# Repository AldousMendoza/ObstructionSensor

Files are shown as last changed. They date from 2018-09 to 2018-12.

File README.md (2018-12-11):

# Obstruction Sensor

This is my first attempt in making a device using the raspberry pi.  
This project mainly presents the VL53L0X ToF(Time of Flight) Distance Sensor.  

A bit of an introduction on how the VL53L0X works:  
The VL53L0X emmits a laser towards a direction.
It then calculates for the distance based on how long the laser bounces back.

## Build Instructions

### System Diagram
The VL53L0X continously reads data(distance) while the SSD1306 continously displays that data.
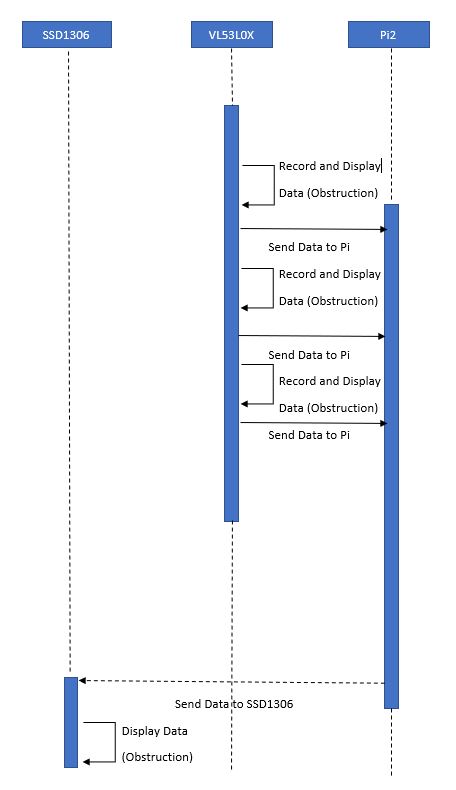
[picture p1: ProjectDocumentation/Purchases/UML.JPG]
  

### [Budget and Parts](https://github.com/AldousMendoza/ObstructionSensor/blob/master/ProjectDocumentation/Budget.xlsx)
You will be needing the following parts in order to create the obstruction sensor:  
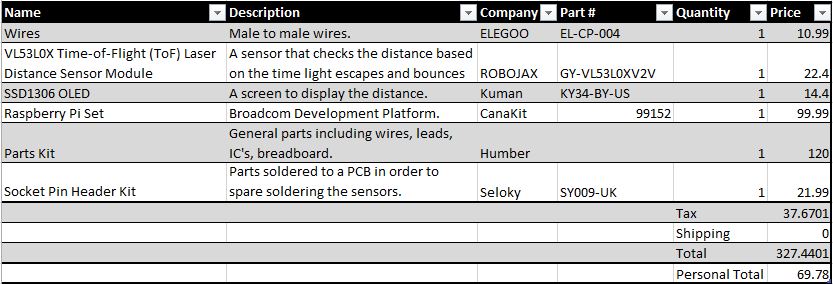
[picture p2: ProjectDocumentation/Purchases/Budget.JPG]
  
NOTE: The Socket Pin Headers are optional, depends if you will be building the PCB or not.  

### Assembly
Raspberry Pi 2 Pin Layout  
  

VL53L0X Pin Layout  
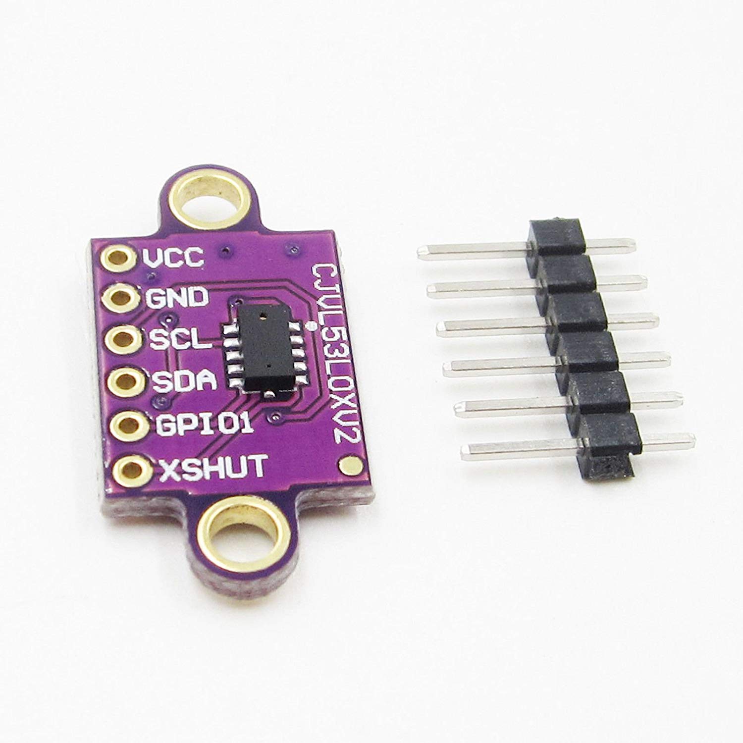
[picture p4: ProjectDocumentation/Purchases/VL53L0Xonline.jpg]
  

SSD1306 Pin Layout  
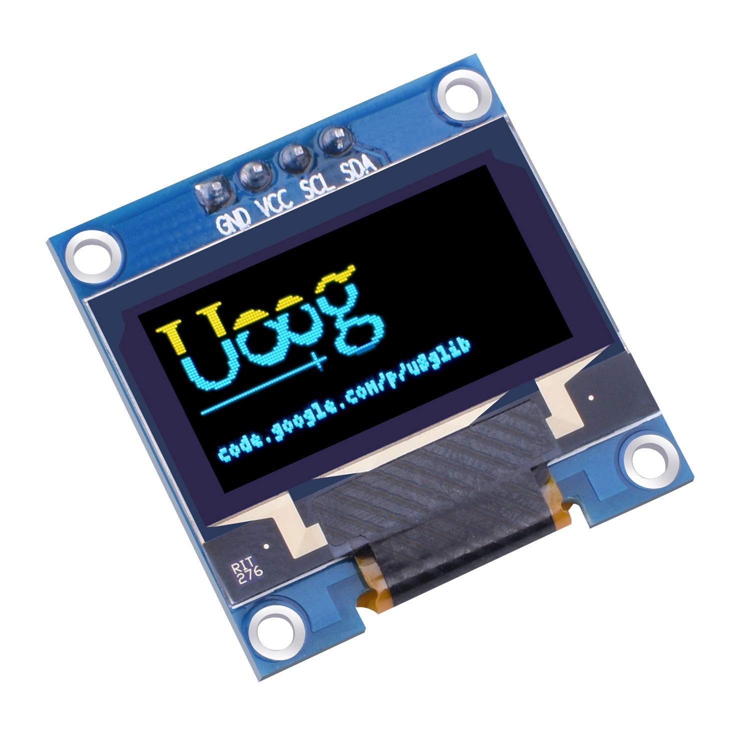
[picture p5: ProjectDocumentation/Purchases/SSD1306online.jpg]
  

1. Connect the VL53L0X and SSD1306's VCC pin to the Raspberry Pi's 3v3 pin.  
2. Connect the  VL53L0X and SSD1306's GND pin to any of the Raspberry Pi's GND pin.  
3. Connect the VL53L0X and SSD1306's SDA pin to the Raspberry Pi's SDA pin.  
4. Connect the VL53L0X and SSD1306's SLA pin to the Raspberry Pi's SLA pin.  

Your assembly should look similar to this:  
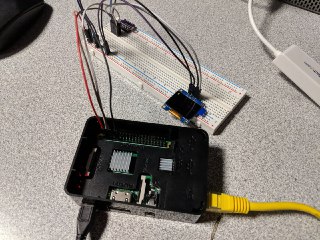
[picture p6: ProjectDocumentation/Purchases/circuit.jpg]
  

### [PCB](https://github.com/AldousMendoza/ObstructionSensor/blob/master/ProjectDocumentation/Obstruction%20Sensor%20PCB%20Sketch.fzz)
This is entirely optional, you do not need this for the device to work.  
For the PCB, you will need the program, Fritzing.  
This is how the PCB will look like this:  
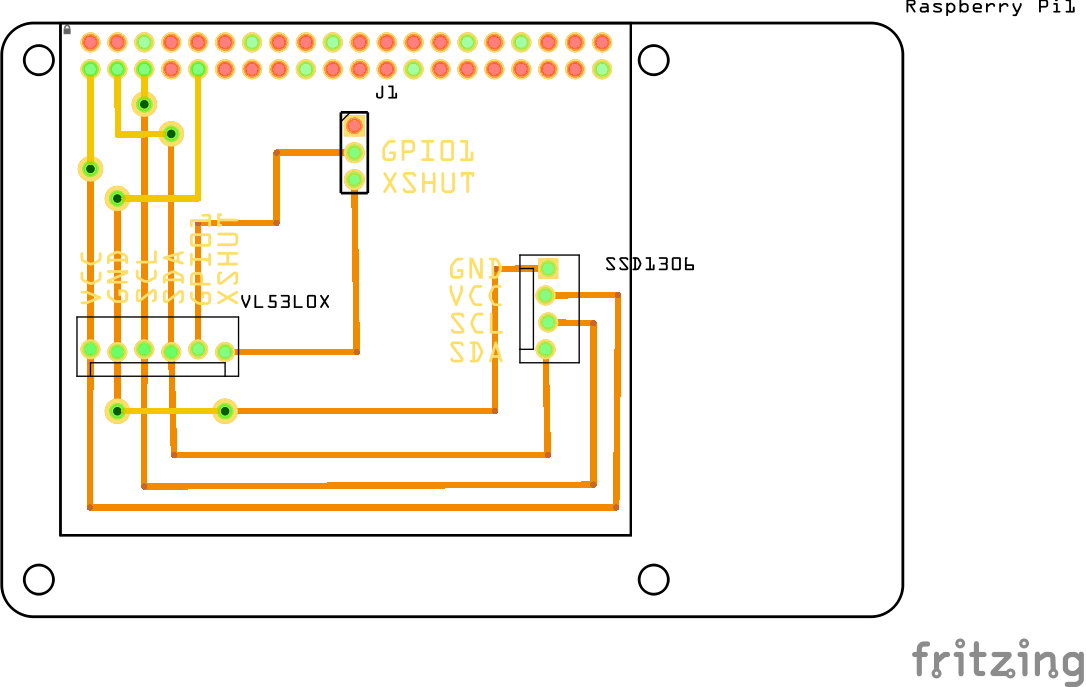
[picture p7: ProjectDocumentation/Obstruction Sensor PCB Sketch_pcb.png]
  

### [Enclosure](https://github.com/AldousMendoza/ObstructionSensor/blob/master/ProjectDocumentation/Pi2CaseX6%20-%20Obstruction%20Sensor.cdr)
This is also optional.  
For the enclosure, we will be using a laser cutter along with the program, CorelDRAW.  
This is how the Enclosure will be:  
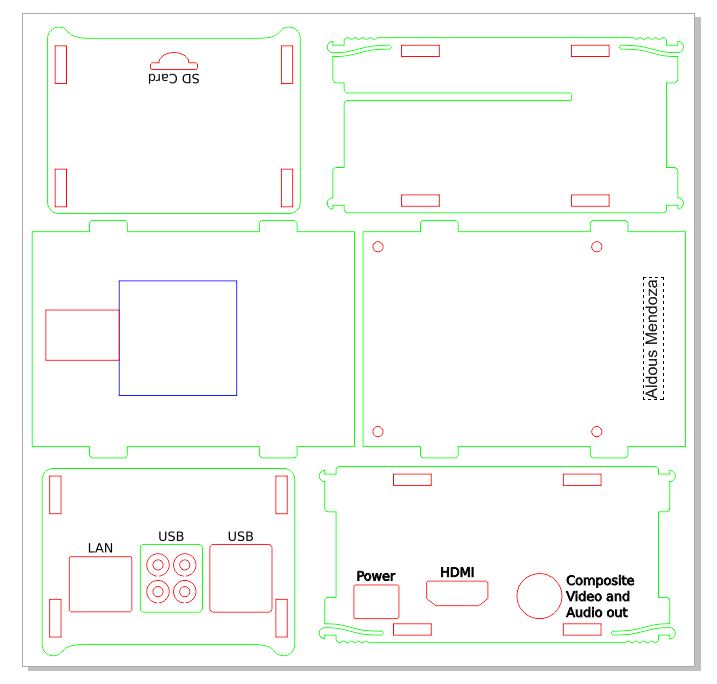
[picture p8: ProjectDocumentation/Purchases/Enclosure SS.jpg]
  

And this is how it looks after assembly:  
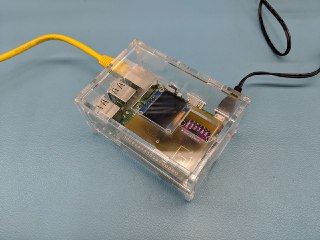
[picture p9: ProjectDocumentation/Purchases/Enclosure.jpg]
  

### Software and Setup

1. Clone and follow the instructions for [VL53L0X](https://github.com/adafruit/Adafruit_CircuitPython_VL53L0X) from [Adafruit](https://github.com/adafruit), credits to them.  
2. Clone and follow the instructions for [SSD1306](https://github.com/adafruit/Adafruit_CircuitPython_SSD1306) from [Adafruit](https://github.com/adafruit), credits to them.  
3. Download all the files in this [folder](https://github.com/AldousMendoza/ObstructionSensor/tree/master/ProjectDocumentation/O-Sensor) to your raspberry pi  

The actual code to run it is the text.py located inside the folder.  
Run it using "Python3 test.py".

### [Schedule](https://github.com/AldousMendoza/ObstructionSensor/blob/master/ProjectDocumentation/Project%20Schedule.mpp)
Having all the parts, and excluding PCB and Enclosure creation times, the project can be made in less than a day.

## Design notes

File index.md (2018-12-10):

## Week 15 : [Build Instructions](https://github.com/AldousMendoza/ObstructionSensor/blob/master/README.md)

## Week 13 - 14 : [Project Presentation](https://github.com/AldousMendoza/ObstructionSensor/blob/master/ProjectDocumentation/Obstruction%20Sensor.pptx)
Updated code to display VL53L0X results to the SSD1306.
The module I acquired did not support text display, only pixel coordinates.
Created code to display numbers 1-10 and 'm' in a 5x10 grid.

## Week 12 : [Enclosure Due](https://github.com/AldousMendoza/ObstructionSensor/blob/master/ProjectDocumentation/Pi2CaseX6%20-%20Obstruction%20Sensor.cdr)
Screenshot of the CorelDRAW file.  
  
This is the finished product.  


## Week 11 : Power-Up Milestone
I have received the socket pin headers and soldered them to my board.
The VL53L0X(ToF) and SSD1306(OLED) are working as intended.
Next in line is to adjust the code to support numbers and a few letters, then to display the distance calculation on the OLED.  
Budget is unchanged.  
Project is now back on [schedule](https://github.com/AldousMendoza/ObstructionSensor/blob/master/ProjectDocumentation/Project%20Schedule.mpp).

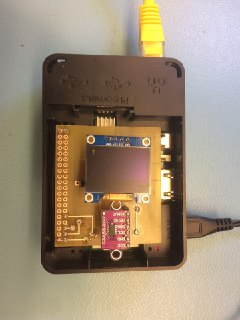
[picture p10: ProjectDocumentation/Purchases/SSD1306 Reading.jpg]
  
SSD1306 - Adafruit's module has no text support, only able to display pixels using coordinate manipulation. Made code to display the letter 'T'.  
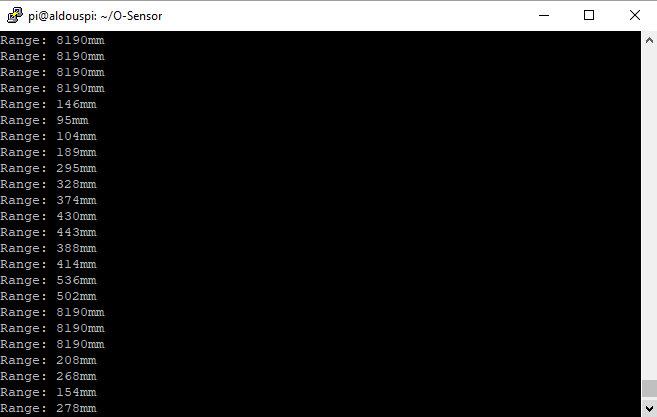
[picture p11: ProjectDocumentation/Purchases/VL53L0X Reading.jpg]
  
VL53L0X - Reading distance and displaying it on the monitor. (in progress: to the OLED)

### Update
[Budget](https://github.com/AldousMendoza/ObstructionSensor/blob/master/ProjectDocumentation/Budget.xlsx) updated.

## Week 10 : PCB Assembly
Unfortunately the item that I purchased was a crimp pin header toolkit.
It was not the part I needed.
I will not count this with my purchased items as I won't be needing this as of yet.
I will be purchasing the socket pin headers sometime this week.
I am now slightly behind [schedule](https://github.com/AldousMendoza/ObstructionSensor/blob/master/ProjectDocumentation/Project%20Schedule.mpp) because of this mishap.
On a sidenote, I was able to acquire a 40x2 socket pin header, and soldered it on my board.

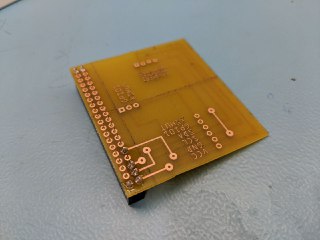
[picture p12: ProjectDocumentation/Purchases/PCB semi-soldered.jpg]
  
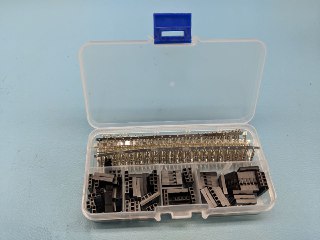
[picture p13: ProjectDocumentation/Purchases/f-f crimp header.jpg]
  
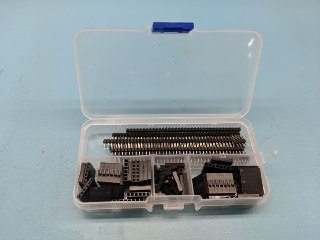
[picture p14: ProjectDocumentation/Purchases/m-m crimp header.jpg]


## Week 9 : [PCB Creation](https://github.com/AldousMendoza/ObstructionSensor/blob/master/ProjectDocumentation/Obstruction%20Sensor%20PCB%20Sketch.fzz)
Gerber file has been sent to prototypelab@humber.ca

### Status Report
Financial Status: Budget has been surpassed.  
Schedule: The project is on [schedule](https://github.com/AldousMendoza/ObstructionSensor/blob/master/ProjectDocumentation/Project%20Schedule.mpp).  
Programming has already been started, trying to figure out how to change the I2C address of the VL53L0X to 24 (default 29) using software.  

  

### UPDATE:  
i2c address table:  
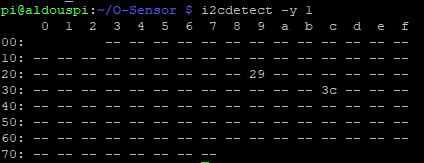
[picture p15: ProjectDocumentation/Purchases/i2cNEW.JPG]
  

Connection has been changed  
  

New Display purchased (SSD1306)  
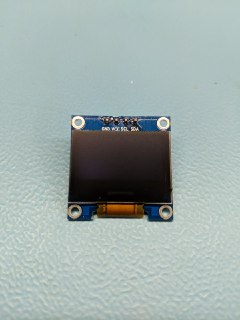
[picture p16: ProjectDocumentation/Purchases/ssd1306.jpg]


## Week 8 : Breadboard

### Resolution
I dropped by Humber's prototype lab to seek help.
The device was still not being detected by their platform.
It doesn't help that we couldn't find the datasheet for the specific board I had, as the device has different setups depending on how the board was laid out.
After troubleshooting and tracing the board, they hinted that one of the pins on the sensor attached to the board had a tiny smudge of solder that connected it to another pin on the sensor.
I am proud to announce that the pins I soldered were not contributing to the issue.
Nonetheless, I will not rule myself out in possibly causing this issue because even though the shorted pins were on the opposite side of the pins I soldered, it is still possible that I have splashed a tiny amount of solder on the opposite side (be very careful on soldering).
After removing they smudge, being as careful as possible as the sensor is very small, the device was now being detected.
Below is the screenshot of the default address it has (0x29).
I still have to change it to 0x24, which will require me more time as it will be changed thru software, rather than hardware.
I am just glad that I did not need to buy another sensor as the shipping fee on Adafruit is expensive.
Shout-outs to Vlad and Kelly as they really saved me here.  
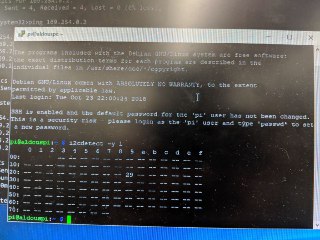
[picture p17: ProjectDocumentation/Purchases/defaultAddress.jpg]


### Issue
The wiring is correct as I tested other's sensors with i2cdetect -y 1, and their devices showed up.
Mine does not show up, I already checked the soldering with the microscope and do not see any issues.
I also checked the voltage on the multimeter and oscilloscope, based on my research, the voltage should spike when using the i2cdetect command.
It is having a constant voltage, which for me, suggests that the board is defective.
I will go and ask help from Kelly and Vlad tomorrow as the lab is closed for today.
If the issue persists after tomorrow, I will purchase a new sensor from Adafruit, a company well trusted.  
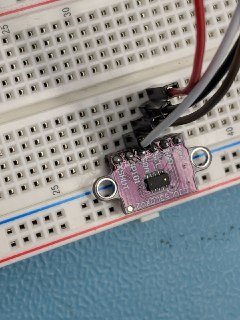
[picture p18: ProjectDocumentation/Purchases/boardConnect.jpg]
  
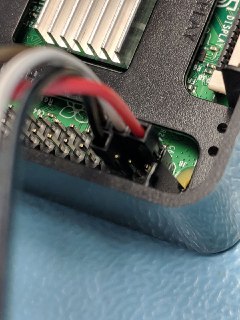
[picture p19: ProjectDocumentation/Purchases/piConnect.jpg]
  
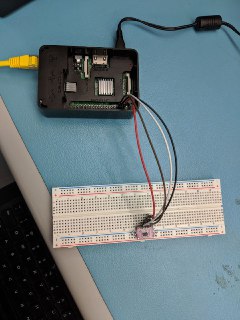
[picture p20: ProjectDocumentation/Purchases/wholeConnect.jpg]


## Week 7 : Purchased Parts
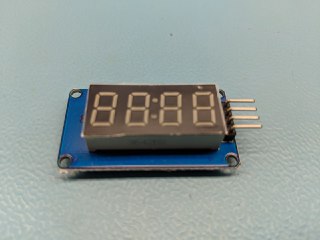
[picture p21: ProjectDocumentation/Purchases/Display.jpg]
  
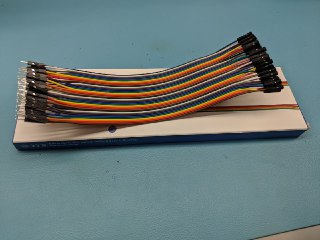
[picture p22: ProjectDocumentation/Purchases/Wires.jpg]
  
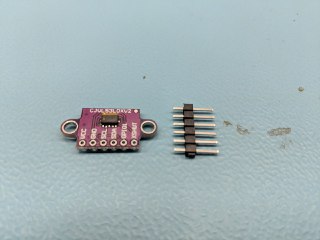
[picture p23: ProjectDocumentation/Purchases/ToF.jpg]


## Week 6 : Holiday

## Week 5 : [Purchases](https://github.com/AldousMendoza/ObstructionSensor/blob/master/ProjectDocumentation/Purchases.docx)  
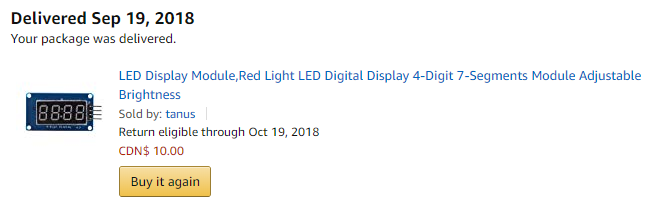
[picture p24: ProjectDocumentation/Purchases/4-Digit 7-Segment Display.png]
  
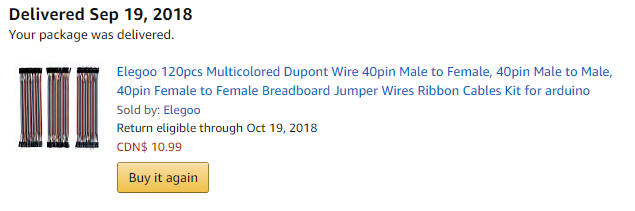
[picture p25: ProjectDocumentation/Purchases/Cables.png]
  
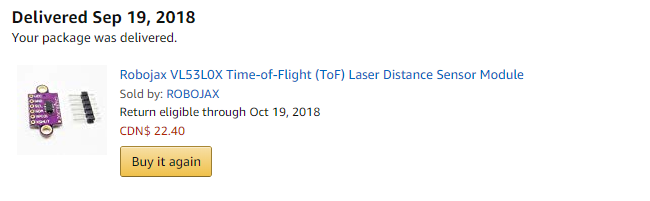
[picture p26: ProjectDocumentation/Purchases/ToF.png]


## Week 4 : [Budget](https://github.com/AldousMendoza/ObstructionSensor/blob/master/ProjectDocumentation/Budget.xlsx)

## Week 3 : [Project Schedule](https://github.com/AldousMendoza/ObstructionSensor/blob/master/ProjectDocumentation/Project%20Schedule.mpp)

## Week 2 : [Project Proposal](https://github.com/AldousMendoza/ObstructionSensor/blob/master/ProjectDocumentation/Project%20Proposal.xlsx)

## Week 1 : Debriefing

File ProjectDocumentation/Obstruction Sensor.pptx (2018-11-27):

## Obstruction Sensor

Aldous Mendoza

## Proposal

Obstruction Sensor (https://aldousmendoza.github.io/ObstructionSensor/)
Automated devices rely on sensors to make majority of their decisions. Self driving devices require obstruction sensors to avoid collisions, and even decide how slow it is going to be.

SSD1306(oLED)
VL53L0X(ToF)


## Budget

Amazon.ca

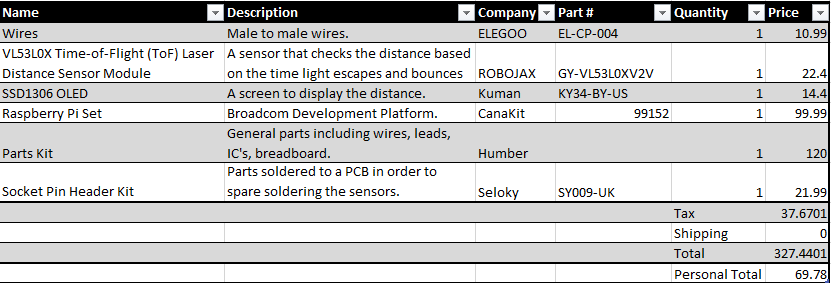
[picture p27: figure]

## Schedule

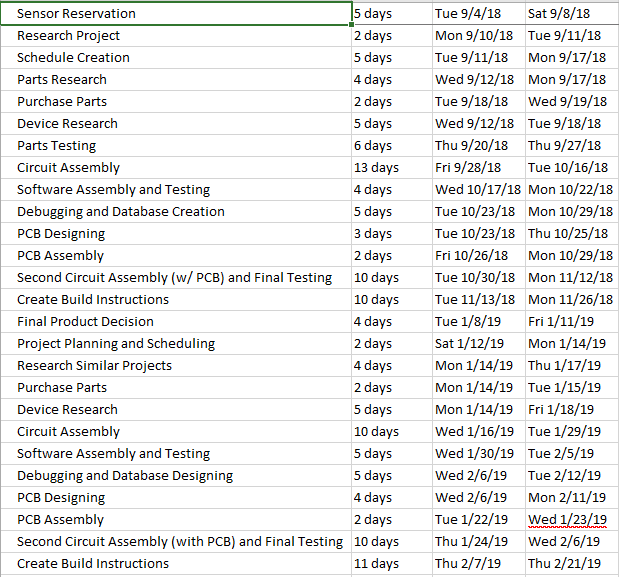
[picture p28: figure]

## Images

Reading
i2c Address
Enclosure

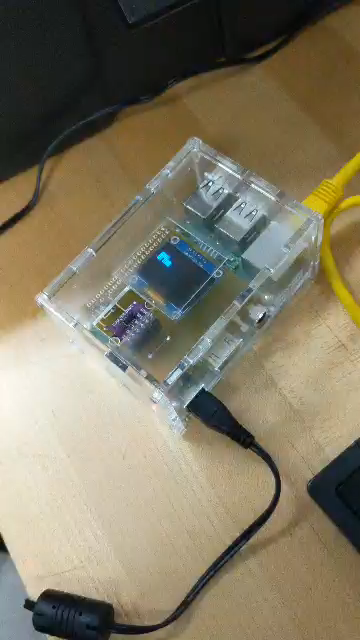
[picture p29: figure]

## Knowledge

- Electric Circuits (TECH101) and Electronic Circuits (CENG150) – assisted with proper circuit building.
- Technical Mathematics 1 (TMTH104) – assisted with problem solving, and algorithms.
- Programming in C (TECH153) and Object Oriented Programming using Java (CENG217)– assisted with learning python.
- Technical Reading and Writing Skills (WRIT120) and Introduction to Software Engineering (CENG216) – assisted with documents.

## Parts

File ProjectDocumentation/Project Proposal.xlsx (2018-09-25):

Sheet: DataEntry
Submission Date | 2018-09-11
Project Name | Obstruction Sensor
Student Name | Aldous Mendoza
Project repository | https://github.com/AldousMendoza/ObstructionSensor
SensorEffector choice | VL53L0x ToF distance (0x24)
The database will store | Obstruction distance. We also plan on storing temparature, and humidity information from the RC car in order to prevent further damage when overheating.
The mobile device functionality will include | A "start" button. We also plan on making an automated RC car that will autodetect obstructions and make its way thru a small maze. The final functionality will most likely consist of "forward" and "reverse" buttons.
I will be collaborating with the following company/department | None
My group in the winter semester will include | Abiodum Ojo, Duke
50 word problem statement | Automated devices do not have their own obstruction sensors. They will need separate modules that are able to give information to the device so that they will be able to prevent collisions.
100 words of background | For automated devices like self driving cars and the like, there is always the issue of collision. Usually, these devices rely on other sensors for it to make the best decision. Without these sensors, the self driving car will always think that it is in the clear and will accelerate even when there is an obstruction, causing accidents.
Current product APA citation | Adafruit (2016, November 23). Adafruit VL53L0X Time of Flight Distance Sensor - ~30 to 1000mm. https://www.adafruit.com/product/3317
Existing research IEEE paper APA citation
Brief description of planned purchases | 1 VL53L0x ToF Distance Sensor, 4 (front, left, right, back) in the winter semester for the RC car.
Solution description | A VL53L0x ToF Distance Sensor calculates the distance from one object to another. In this case, the RC car to any kind of obstruction. After getting information (distance) from the device, through appropriate programming, the RC car should turn accordingly. Multiple sensors will guide the RC car to make the best decision (turning left, turning right, or even a complete stop).

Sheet: DataBase
Submission Date | Project Name | Student Name | Project repository | SensorEffector choice | The database will store | The mobile device functionality will include | I will be collaborating with the following company/department | My group in the winter semester will include | 50 word problem statement | 100 words of background | Current product APA citation | Existing research IEEE paper APA citation | Brief description of planned purchases | Solution description
43354 | Obstruction Sensor | Aldous Mendoza | https://github.com/AldousMendoza/ObstructionSensor | VL53L0x ToF distance (0x24) | Obstruction distance. We also plan on storing temparature, and humidity information from the RC car in order to prevent further damage when overheating. | A "start" button. We also plan on making an automated RC car that will autodetect obstructions and make its way thru a small maze. The final functionality will most likely consist of "forward" and "reverse" buttons. | None | Abiodum Ojo, Duke | Automated devices do not have their own obstruction sensors. They will need separate modules that are able to give information to the device so that they will be able to prevent collisions. | For automated devices like self driving cars and the like, there is always the issue of collision. Usually, these devices rely on other sensors for it to make the best decision. Without these sensors, the self driving car will always think that it is in the clear and will accelerate even when there is an obstruction, causing accidents. | Adafruit (2016, November 23). Adafruit VL53L0X Time of Flight Distance Sensor - ~30 to 1000mm. https://www.adafruit.com/product/3317 | 0 | 1 VL53L0x ToF Distance Sensor, 4 (front, left, right, back) in the winter semester for the RC car. | A VL53L0x ToF Distance Sensor calculates the distance from one object to another. In this case, the RC car to any kind of obstruction. After getting information (distance) from the device, through appropriate programming, the RC car should turn accordingly. Multiple sensors will guide the RC car to make the best decision (turning left, turning right, or even a complete stop).

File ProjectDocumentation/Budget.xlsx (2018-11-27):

Obstruction Sensor Budget
Name | Description | Company | Part # | Quantity | Price
Wires | Male to male wires. | ELEGOO | EL-CP-004 | 1 | 10.99
VL53L0X Time-of-Flight (ToF) Laser Distance Sensor Module | A sensor that checks the distance based on the time light escapes and bounces back. | ROBOJAX | GY-VL53L0XV2V | 1 | 22.4
SSD1306 OLED | A screen to display the distance. | Kuman | KY34-BY-US | 1 | 14.4
Raspberry Pi Set | Broadcom Development Platform. | CanaKit | 99152 | 1 | 99.99
Parts Kit | General parts including wires, leads, IC's, breadboard. | Humber |  | 1 | 120
Socket Pin Header Kit | Parts soldered to a PCB in order to spare soldering the sensors. | Seloky | SY009-UK | 1 | 21.99
 |  |  |  | Tax | 37.6701
 |  |  |  | Shipping | 0
 |  |  |  | Total | 327.4401
 |  |  |  | Personal Total | 69.78
Aldous Mendoza

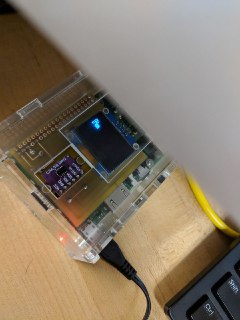
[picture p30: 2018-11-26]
ProjectDocumentation/Purchases/displayReading.jpg

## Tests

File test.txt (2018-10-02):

## Obstruction Sensor

### Week 5 -[Submitted Purchases](https://github.com/AldousMendoza/ObstructionSensor/blob/master/ProjectDocumentation/Purchases.docx)  
  
  
  

### Week 4 - [Submitted Budget](https://github.com/AldousMendoza/ObstructionSensor/blob/master/ProjectDocumentation/Budget.xlsx)

### Week 3 - [Submitted Project Schedule](https://github.com/AldousMendoza/ObstructionSensor/blob/master/ProjectDocumentation/Project%20Schedule.mpp)

### Week 2 - [Submitted Project Proposal](https://github.com/AldousMendoza/ObstructionSensor/blob/master/ProjectDocumentation/Project%20Proposal.xlsx)

### Week 1 - Debriefing

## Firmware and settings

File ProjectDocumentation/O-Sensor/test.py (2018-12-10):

# Test demo
import time

import board
import busio

import adafruit_ssd1306
import adafruit_vl53l0x

# Initialize I2C bus
i2c = busio.I2C(board.SCL, board.SDA)
vl53 = adafruit_vl53l0x.VL53L0X(i2c)
oled = adafruit_ssd1306.SSD1306_I2C(128, 32, i2c)

text = 'Hello'

#make a stupid-ass letter 'T'
#make it 6x6 and with 2 pixels thick
oled.fill(0)
#oled.pixel(0,0,1)
#oled.pixel(1,0,1)
#oled.pixel(2,0,1)
#oled.pixel(3,0,1)
#oled.pixel(4,0,1)
#oled.pixel(2,1,1)
#oled.pixel(2,2,1)
#oled.pixel(2,3,1)
#oled.pixel(2,4,1)
#oled.show()

# Optionally adjust the measurement timing budget to change speed and accuracy.
# See the example here for more details:
#   https://github.com/pololu/vl53l0x-arduino/blob/master/examples/Single/Single.ino
# For example a higher speed but less accurate timing budget of 20ms:
#vl53.measurement_timing_budget = 20000
# Or a slower but more accurate timing budget of 200ms:
#vl53.measurement_timing_budget = 200000
# The default timing budget is 33ms, a good compromise of speed and accuracy.

# Main loop will read the range and print it every second.
while True:
    time.sleep(1.0)
    num = 0
    xStart = 0
    yStart = 8
    range = format(vl53.range)
    print('Range: %smm' % (range))

    L = list(range)
    for x in L:
        if x == '0':
            oled.pixel(xStart, yStart, 1)
            oled.pixel(xStart, yStart + 1, 1)
            oled.pixel(xStart, yStart + 2, 1)
            oled.pixel(xStart, yStart + 3, 1)
            oled.pixel(xStart, yStart + 4, 1)
            oled.pixel(xStart, yStart + 5, 1)
            oled.pixel(xStart, yStart + 6, 1)
            oled.pixel(xStart, yStart + 7, 1)
            oled.pixel(xStart, yStart + 8, 1)
            oled.pixel(xStart, yStart + 9, 1)
            oled.pixel(xStart + 1, yStart, 1)
            oled.pixel(xStart + 1, yStart + 9, 1)
            oled.pixel(xStart + 2, yStart, 1)
            oled.pixel(xStart + 2, yStart + 9, 1)
            oled.pixel(xStart + 3, yStart, 1)
            oled.pixel(xStart + 3, yStart + 9, 1)
            oled.pixel(xStart + 4, yStart, 1)
            oled.pixel(xStart + 4, yStart + 1, 1)
            oled.pixel(xStart + 4, yStart + 2, 1)
            oled.pixel(xStart + 4, yStart + 3, 1)
            oled.pixel(xStart + 4, yStart + 4, 1)
            oled.pixel(xStart + 4, yStart + 5, 1)
            oled.pixel(xStart + 4, yStart + 6, 1)
            oled.pixel(xStart + 4, yStart + 7, 1)
            oled.pixel(xStart + 4, yStart + 8, 1)
            oled.pixel(xStart + 4, yStart + 9, 1)
        if x == '1':
            oled.pixel(xStart + 2, yStart, 1)
            oled.pixel(xStart + 2, yStart + 1, 1)
            oled.pixel(xStart + 2, yStart + 2, 1)
            oled.pixel(xStart + 2, yStart + 3, 1)
            oled.pixel(xStart + 2, yStart + 4, 1)
            oled.pixel(xStart + 2, yStart + 5, 1)
            oled.pixel(xStart + 2, yStart + 6, 1)
            oled.pixel(xStart + 2, yStart + 7, 1)
            oled.pixel(xStart + 2, yStart + 8, 1)
            oled.pixel(xStart + 2, yStart + 9, 1)
        if x == '2':
            oled.pixel(xStart, yStart, 1)
            oled.pixel(xStart + 1, yStart, 1)
            oled.pixel(xStart + 2, yStart, 1)
            oled.pixel(xStart + 3, yStart, 1)
            oled.pixel(xStart + 4, yStart, 1)
            oled.pixel(xStart + 4, yStart + 1, 1)
            oled.pixel(xStart + 4, yStart + 2, 1)
            oled.pixel(xStart + 4, yStart + 3, 1)
            oled.pixel(xStart + 4, yStart + 4, 1)
            oled.pixel(xStart + 3, yStart + 4, 1)
            oled.pixel(xStart + 2, yStart + 4, 1)
            oled.pixel(xStart + 1, yStart + 4, 1)
            oled.pixel(xStart, yStart + 4, 1)
            oled.pixel(xStart, yStart + 5, 1)
            oled.pixel(xStart, yStart + 6, 1)
            oled.pixel(xStart, yStart + 7, 1)
            oled.pixel(xStart, yStart + 8, 1)
            oled.pixel(xStart, yStart + 9, 1)
            oled.pixel(xStart + 1, yStart + 9, 1)
            oled.pixel(xStart + 2, yStart + 9, 1)
            oled.pixel(xStart + 3, yStart + 9, 1)
            oled.pixel(xStart + 4, yStart + 9, 1)
        if x == '3':
            oled.pixel(xStart, yStart, 1)
            oled.pixel(xStart + 1, yStart, 1)
            oled.pixel(xStart + 2, yStart, 1)
            oled.pixel(xStart + 3, yStart, 1)
            oled.pixel(xStart + 4, yStart, 1)
            oled.pixel(xStart + 4, yStart + 1, 1)
            oled.pixel(xStart + 4, yStart + 2, 1)
            oled.pixel(xStart + 4, yStart + 3, 1)
            oled.pixel(xStart + 4, yStart + 4, 1)
            oled.pixel(xStart + 3, yStart + 4, 1)
            oled.pixel(xStart + 2, yStart + 4, 1)
            oled.pixel(xStart + 1, yStart + 4, 1)
            oled.pixel(xStart, yStart + 4, 1)
            oled.pixel(xStart + 4, yStart + 5, 1)
            oled.pixel(xStart + 4, yStart + 6, 1)
            oled.pixel(xStart + 4, yStart + 7, 1)
            oled.pixel(xStart + 4, yStart + 8, 1)
            oled.pixel(xStart + 4, yStart + 9, 1)
            oled.pixel(xStart + 3, yStart + 9, 1)
            oled.pixel(xStart + 2, yStart + 9, 1)
            oled.pixel(xStart + 1, yStart + 9, 1)
            oled.pixel(xStart, yStart + 9, 1)
        if x == '4':
            oled.pixel(xStart, yStart, 1)
            oled.pixel(xStart, yStart + 1, 1)
            oled.pixel(xStart, yStart + 2, 1)
            oled.pixel(xStart, yStart + 3, 1)
            oled.pixel(xStart, yStart + 4, 1)
            oled.pixel(xStart + 1, yStart + 4, 1)
            oled.pixel(xStart + 2, yStart + 4, 1)
            oled.pixel(xStart + 3, yStart + 4, 1)
            oled.pixel(xStart + 4, yStart + 4, 1)
            oled.pixel(xStart + 4, yStart + 3, 1)
            oled.pixel(xStart + 4, yStart + 2, 1)
            oled.pixel(xStart + 4, yStart + 1, 1)
            oled.pixel(xStart + 4, yStart, 1)
            oled.pixel(xStart + 4, yStart + 5, 1)
            oled.pixel(xStart + 4, yStart + 6, 1)
            oled.pixel(xStart + 4, yStart + 7, 1)
            oled.pixel(xStart + 4, yStart + 8, 1)
            oled.pixel(xStart + 4, yStart + 9, 1)
        if x == '5':
            oled.pixel(xStart, yStart, 1)
            oled.pixel(xStart + 1, yStart, 1)
            oled.pixel(xStart + 2, yStart, 1)
            oled.pixel(xStart + 3, yStart, 1)
            oled.pixel(xStart + 4, yStart, 1)
            oled.pixel(xStart, yStart + 1, 1)
            oled.pixel(xStart, yStart + 2, 1)
            oled.pixel(xStart, yStart + 3, 1)
            oled.pixel(xStart, yStart + 4, 1)
            oled.pixel(xStart + 1, yStart + 4, 1)
            oled.pixel(xStart + 2, yStart + 4, 1)
            oled.pixel(xStart + 3, yStart + 4, 1)
            oled.pixel(xStart + 4, yStart + 4, 1)
            oled.pixel(xStart + 4, yStart + 5, 1)
            oled.pixel(xStart + 4, yStart + 6, 1)
            oled.pixel(xStart + 4, yStart + 7, 1)
            oled.pixel(xStart + 4, yStart + 8, 1)
            oled.pixel(xStart + 4, yStart + 9, 1)
            oled.pixel(xStart + 3, yStart + 9, 1)
            oled.pixel(xStart + 2, yStart + 9, 1)
            oled.pixel(xStart + 1, yStart + 9, 1)
            oled.pixel(xStart, yStart + 9, 1)
        if x == '6':
            oled.pixel(xStart, yStart, 1)
            oled.pixel(xStart + 1, yStart, 1)
            oled.pixel(xStart + 2, yStart, 1)
            oled.pixel(xStart + 3, yStart, 1)
            oled.pixel(xStart + 4, yStart, 1)
            oled.pixel(xStart, yStart + 1, 1)
            oled.pixel(xStart, yStart + 2, 1)
            oled.pixel(xStart, yStart + 3, 1)
            oled.pixel(xStart, yStart + 4, 1)
            oled.pixel(xStart + 1, yStart + 4, 1)
            oled.pixel(xStart + 2, yStart + 4, 1)
            oled.pixel(xStart + 3, yStart + 4, 1)
            oled.pixel(xStart + 4, yStart + 4, 1)
            oled.pixel(xStart + 4, yStart + 5, 1)
            oled.pixel(xStart + 4, yStart + 6, 1)
            oled.pixel(xStart + 4, yStart + 7, 1)
            oled.pixel(xStart + 4, yStart + 8, 1)
            oled.pixel(xStart + 4, yStart + 9, 1)
            oled.pixel(xStart + 3, yStart + 9, 1)
            oled.pixel(xStart + 2, yStart + 9, 1)
            oled.pixel(xStart + 1, yStart + 9, 1)
            oled.pixel(xStart, yStart + 9, 1)
            oled.pixel(xStart, yStart + 8, 1)
            oled.pixel(xStart, yStart + 7, 1)
            oled.pixel(xStart, yStart + 6, 1)
            oled.pixel(xStart, yStart + 5, 1)
        if x == '7':
            oled.pixel(xStart, yStart, 1)
            oled.pixel(xStart + 1, yStart, 1)
            oled.pixel(xStart + 2, yStart, 1)
            oled.pixel(xStart + 3, yStart, 1)
            oled.pixel(xStart + 4, yStart, 1)
            oled.pixel(xStart + 4, yStart + 1, 1)
            oled.pixel(xStart + 4, yStart + 2, 1)
            oled.pixel(xStart + 4, yStart + 3, 1)
            oled.pixel(xStart + 4, yStart + 4, 1)
            oled.pixel(xStart + 4, yStart + 5, 1)
            oled.pixel(xStart + 4, yStart + 6, 1)
            oled.pixel(xStart + 4, yStart + 7, 1)
            oled.pixel(xStart + 4, yStart + 8, 1)
            oled.pixel(xStart + 4, yStart + 9, 1)
        if x == '8':
            oled.pixel(xStart, yStart, 1)
            oled.pixel(xStart + 1, yStart, 1)
            oled.pixel(xStart + 2, yStart, 1)
            oled.pixel(xStart + 3, yStart, 1)
            oled.pixel(xStart + 4, yStart, 1)
            oled.pixel(xStart + 4, yStart + 1, 1)
            oled.pixel(xStart + 4, yStart + 2, 1)
            oled.pixel(xStart + 4, yStart + 3, 1)
            oled.pixel(xStart + 4, yStart + 4, 1)
            oled.pixel(xStart + 4, yStart + 5, 1)
            oled.pixel(xStart + 4, yStart + 6, 1)
            oled.pixel(xStart + 4, yStart + 7, 1)
            oled.pixel(xStart + 4, yStart + 8, 1)
            oled.pixel(xStart + 4, yStart + 9, 1)
            oled.pixel(xStart + 3, yStart + 9, 1)
            oled.pixel(xStart + 2, yStart + 9, 1)
            oled.pixel(xStart + 1, yStart + 9, 1)
            oled.pixel(xStart, yStart + 9, 1)
            oled.pixel(xStart, yStart + 8, 1)
            oled.pixel(xStart, yStart + 7, 1)
            oled.pixel(xStart, yStart + 6, 1)
            oled.pixel(xStart, yStart + 5, 1)
            oled.pixel(xStart, yStart + 4, 1)
            oled.pixel(xStart, yStart + 3, 1)
            oled.pixel(xStart, yStart + 2, 1)
            oled.pixel(xStart, yStart + 1, 1)
            oled.pixel(xStart, yStart, 1)
            oled.pixel(xStart + 1, yStart + 4, 1)
            oled.pixel(xStart + 2, yStart + 4, 1)
            oled.pixel(xStart + 3, yStart + 4, 1)
        if x == '9':
            oled.pixel(xStart, yStart, 1)
            oled.pixel(xStart + 1, yStart, 1)
            oled.pixel(xStart + 2, yStart, 1)
            oled.pixel(xStart + 3, yStart, 1)
            oled.pixel(xStart + 4, yStart, 1)
            oled.pixel(xStart + 4, yStart + 1, 1)
            oled.pixel(xStart + 4, yStart + 2, 1)
            oled.pixel(xStart + 4, yStart + 3, 1)
            oled.pixel(xStart + 4, yStart + 4, 1)
            oled.pixel(xStart + 3, yStart + 4, 1)
            oled.pixel(xStart + 2, yStart + 4, 1)
            oled.pixel(xStart + 1, yStart + 4, 1)
            oled.pixel(xStart, yStart + 4, 1)
            oled.pixel(xStart, yStart + 3, 1)
            oled.pixel(xStart, yStart + 2, 1)
            oled.pixel(xStart, yStart + 1, 1)
            oled.pixel(xStart + 4, yStart + 5, 1)
            oled.pixel(xStart + 4, yStart + 6, 1)
            oled.pixel(xStart + 4, yStart + 7, 1)
            oled.pixel(xStart + 4, yStart + 8, 1)
            oled.pixel(xStart + 4, yStart + 9, 1)

        num += 1
        xStart += 6

    oled.pixel(xStart, yStart + 4, 1)
    oled.pixel(xStart, yStart + 5, 1)
    oled.pixel(xStart, yStart + 6, 1)
    oled.pixel(xStart, yStart + 7, 1)
    oled.pixel(xStart, yStart + 8, 1)
    oled.pixel(xStart, yStart + 9, 1)
    oled.pixel(xStart + 1, yStart + 5, 1)
    oled.pixel(xStart + 2, yStart + 4, 1)
    oled.pixel(xStart + 2, yStart + 5, 1)
    oled.pixel(xStart + 2, yStart + 6, 1)
    oled.pixel(xStart + 2, yStart + 7, 1)
    oled.pixel(xStart + 2, yStart + 8, 1)
    oled.pixel(xStart + 2, yStart + 9, 1)
    oled.pixel(xStart + 3, yStart + 5, 1)
    oled.pixel(xStart + 4, yStart + 6, 1)
    oled.pixel(xStart + 4, yStart + 7, 1)
    oled.pixel(xStart + 4, yStart + 8, 1)
    oled.pixel(xStart + 4, yStart + 9, 1)

    num += 1
    xStart += 6

    oled.pixel(xStart, yStart + 4, 1)
    oled.pixel(xStart, yStart + 5, 1)
    oled.pixel(xStart, yStart + 6, 1)
    oled.pixel(xStart, yStart + 7, 1)
    oled.pixel(xStart, yStart + 8, 1)
    oled.pixel(xStart, yStart + 9, 1)
    oled.pixel(xStart + 1, yStart + 5, 1)
    oled.pixel(xStart + 2, yStart + 4, 1)
    oled.pixel(xStart + 2, yStart + 5, 1)
    oled.pixel(xStart + 2, yStart + 6, 1)
    oled.pixel(xStart + 2, yStart + 7, 1)
    oled.pixel(xStart + 2, yStart + 8, 1)
    oled.pixel(xStart + 2, yStart + 9, 1)
    oled.pixel(xStart + 3, yStart + 5, 1)
    oled.pixel(xStart + 4, yStart + 6, 1)
    oled.pixel(xStart + 4, yStart + 7, 1)
    oled.pixel(xStart + 4, yStart + 8, 1)
    oled.pixel(xStart + 4, yStart + 9, 1)

    num += 1
    xStart += 6

    oled.show()
    oled.fill(0)
